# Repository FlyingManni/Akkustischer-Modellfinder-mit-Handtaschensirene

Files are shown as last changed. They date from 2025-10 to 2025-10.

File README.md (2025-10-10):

# Modellfinder (Ansteuerung eines Taschenalarms)

Um verloren gegangene Modelle leichter wiederzufinden (besonders im Maisfeld), kam die Idee,  
einen Taschenalarm zu verwenden. Um diesen gezielt auszulösen, benötigt man eine entsprechende  
Ansteuerung — hier kommt der **Tiny45 Modellfinder** zum Einsatz.

---

## 🧭 Tiny45 Steuerung

Der Modellfinder wird über einen freien Empfängerkanal gesteuert.  
Hierbei gibt es vier mögliche Zustände:

1. **Empfängersignal kleiner 1,4 ms**  
   → Schaltet den Alarm scharf und ist ausgeschaltet.  
   Solange nicht mindestens einmalig ein Signal unter 1,4 ms anlag, ist keine Alarmierung möglich.  
   Wenn der Alarm *scharf* und ausgeschaltet ist, leuchtet die **Status-LED dauerhaft**.

2. **Signal zwischen 1,4 und 1,7 ms**  
   → Das sollte auch die *Failsafe-Einstellung* sein.  
   Liegt dieses Signal an, startet ein **1-minütiger Timer**.  
   Nach Ablauf von 1 Minute wird der Alarm ausgelöst.  
   Während der Timer läuft, **blinkt die Status-LED schnell**.

3. **Signal über 1,7 ms**  
   → Es wird **sofort Alarm ausgelöst**.  
   Die **Status-LED blinkt langsam**.

4. **Kein Signal mehr vom Empfänger**  
   (z. B. wenn der Flugakku vom Modell getrennt wurde)  
   → Ablauf wie bei Zustand 2.

> 🧩 **Anmerkung:**  
> Zustände 2 bis 4 sind erst möglich, wenn zuvor einmal Zustand 1 hergestellt wurde  
> (also ein Empfängersignal unter 1,4 ms anlag).

---

## 🔌 Anschlussübersicht

| Pin | Funktion / Anschlussbeschreibung |
|---|---|
| **RC-Signal** | An einen Empfängerausgang (Signal) anschließen |
| **RC-GND** | Masse des Empfängerausgangs |
| **+UB** | Betriebsspannung des Alarmgebers **max. 5V** (nicht direkt an Batterie-Plus anschließen, sondern an die Buchse, über die der Alarm ursprünglich ausgelöst wird – sonst ist die Steuerung ständig aktiv und die Batterie bald leer) |
| **Alarm** | Schaltet gegen Masse – hier wird die vorhandene Alarmschaltung angeschlossen |
| **GND** | Direkt an den Minuspol der Batterie anschließen |

---

## 📦 Tiny45 Steuerung

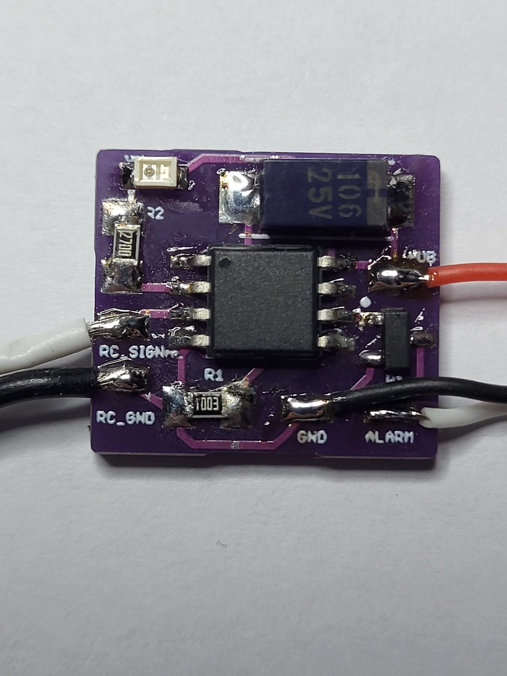
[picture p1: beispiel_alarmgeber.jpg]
Beispiel-Alarmgeber


---

## 📘 Lizenz & Hinweise

Dieses Projekt ist für den privaten Gebrauch gedacht.  
Verwendung auf eigene Verantwortung.

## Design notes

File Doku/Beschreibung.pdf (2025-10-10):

### Modellfinder (Ansteuerung eines Taschenalarms)

Um verloren gegangene Modelle leichter wieder zu finden (besonders im Maisfeld), kam die Idee einen Taschenalarm zu verwenden. Um diesen gezielt auszulösen benötigt man eine entsprechende Ansteuerung, hier kommt der Tiny45 Modellfinder zum Zug.

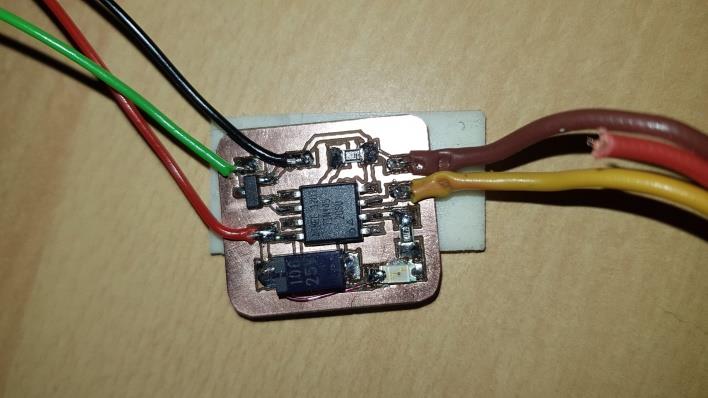
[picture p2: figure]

Tiny45 Steuerung 1

Der Modellfinder wird über einen freien Empfängerkanal gesteuert. Hierbei gibt es 4 mögliche Zustände:

1. Empfängersignal kleiner 1,4 ms -> schaltet den Alarm scharf und ist ausgeschaltet. Solange nicht mindestens einmalig ein Signal unter 1,4 ms angelegen hat ist keine Alarmierung möglich. Wenn der Alarm „scharf“ und ausgeschaltet ist leuchtet die Status-LED dauerhaft.
2. Signal zwischen 1,4 und 1,7 ms -> das sollte auch die Failsafe-Einstellung sein. Liegt dieses Signal an startet ein 1 minütiger Timer. Nach Ablauf von 1 Minute wird Alarm ausgelöst. Während der Timer läuft blinkt die Status-LED schnell.
3. Signal über 1,7 ms -> es wird sofort Alarm ausgelöst. Die Status-LED blinkt langsam.
4. Kein Signal mehr vom Empfänger (Flugakku wurde vom Modell getrennt) -> Ablauf wie bei 2.

Anmerkung: Zustände 2 bis 4 sind erst möglich wenn zuvor einmal Zustand 1 hergestellt wurde, also ein Empfängersignal unter 1,4 ms.

Verbunden wird die Steuerung wie folgt:

Pin „RC-Signal“ an einen Empfängerausgang (Signal)
Pin „RC-GND“ Masse des Empfängerausgangs
Pin „+UB“ an die Betriebsspannung des Alarmgebers, hier ist darauf zu achten nicht direkt an den Pluspol der Batterie anzuschließen sondern an die entsprechende Buchse durch den ursprünglich der Alarm ausgelöst wird, sonst ist die Steuerung immer „an“ und die Batterie bald leer.
Pin „Alarm“ schaltet gegen „Masse“, d.h. hier wird die vorhandene Alarmschaltung angeschlossen. Pin „GND“ wird direkt an den Minuspol der Batterie angeschlossen.

Beispiel eines Alarmgebers wie man ihn in diversen Verkaufsportalen kaufen kann:

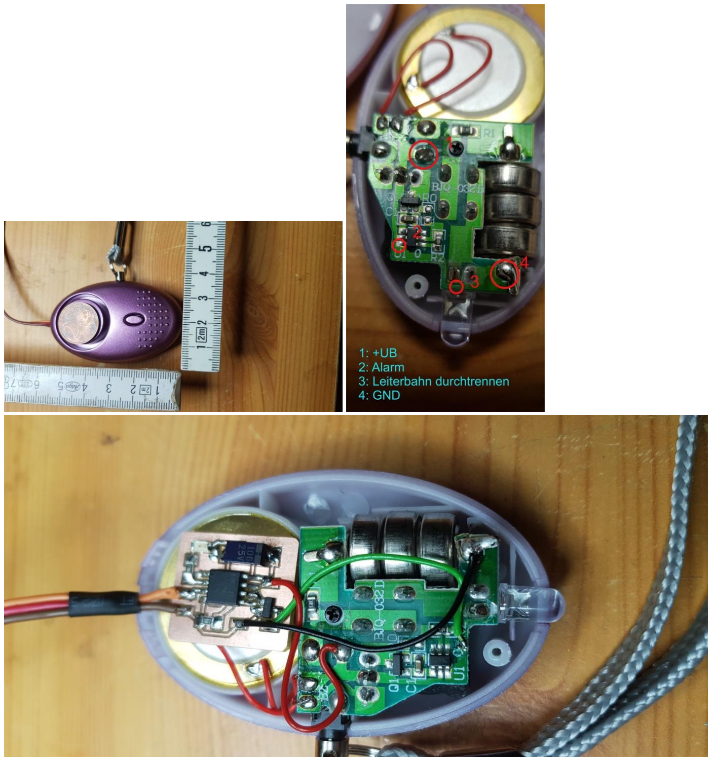
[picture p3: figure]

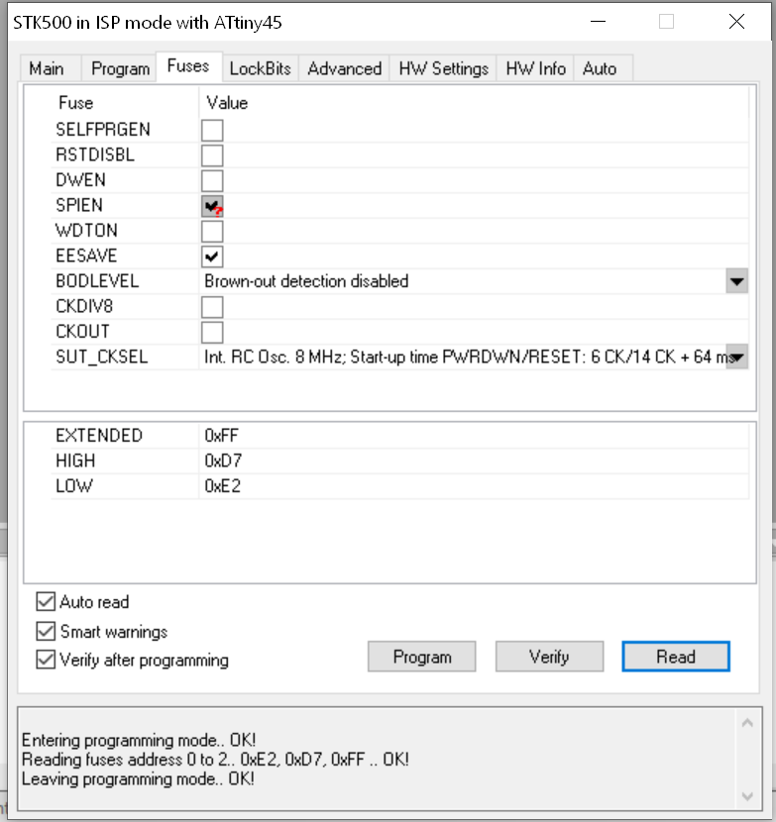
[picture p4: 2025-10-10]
Hex/Modellfinder_Tiny_Fuses.PNG

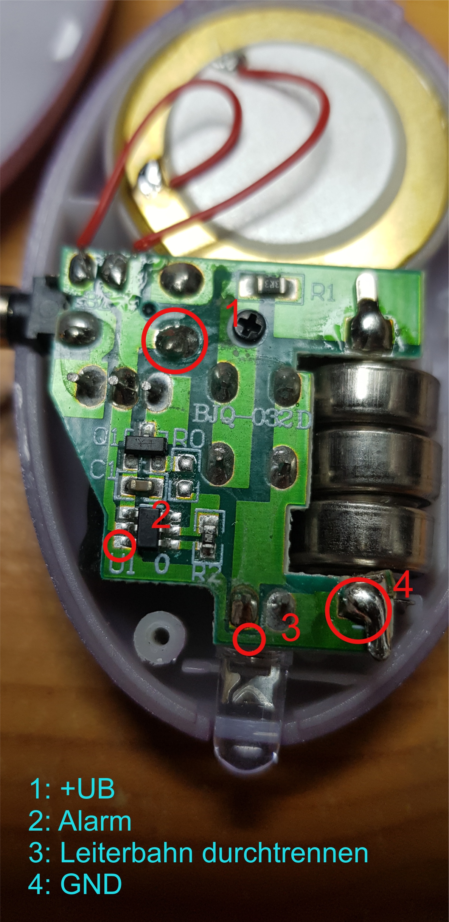
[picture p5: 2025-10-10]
Doku/Anschluesse.jpg

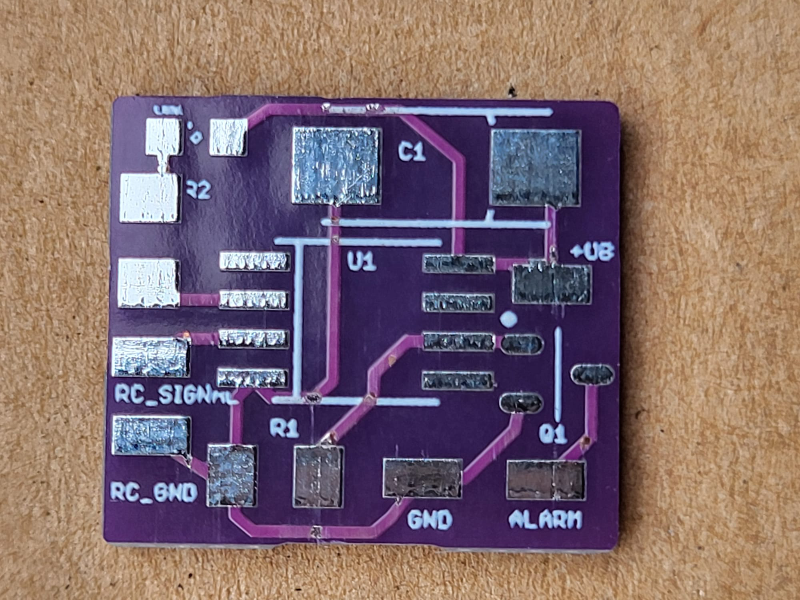
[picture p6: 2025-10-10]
Eagle/Platine.jpeg

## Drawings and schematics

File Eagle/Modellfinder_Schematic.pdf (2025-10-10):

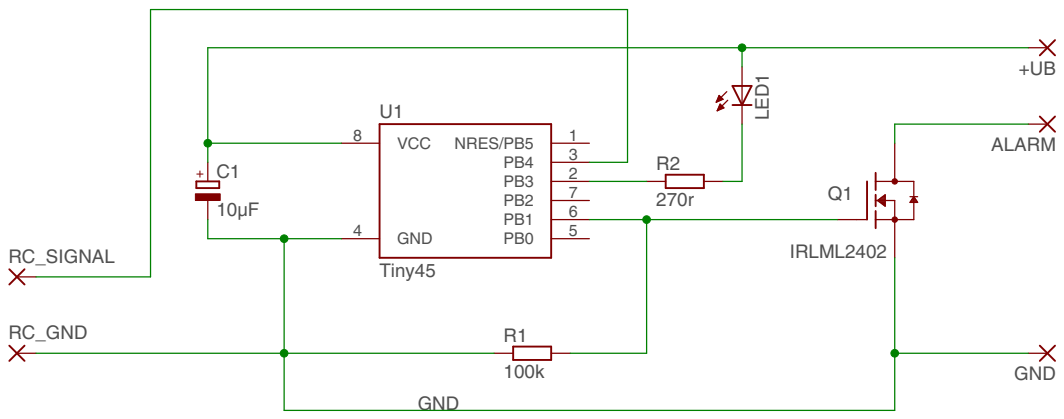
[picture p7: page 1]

Document Number: | REV:

Date: 23.10.2020 16:31 | Sheet: 1/1

23.10.2020 16:32 D:\Tortoise\Modellfinder\Eagle\Modellfinder.sch (Sheet: 1/1)

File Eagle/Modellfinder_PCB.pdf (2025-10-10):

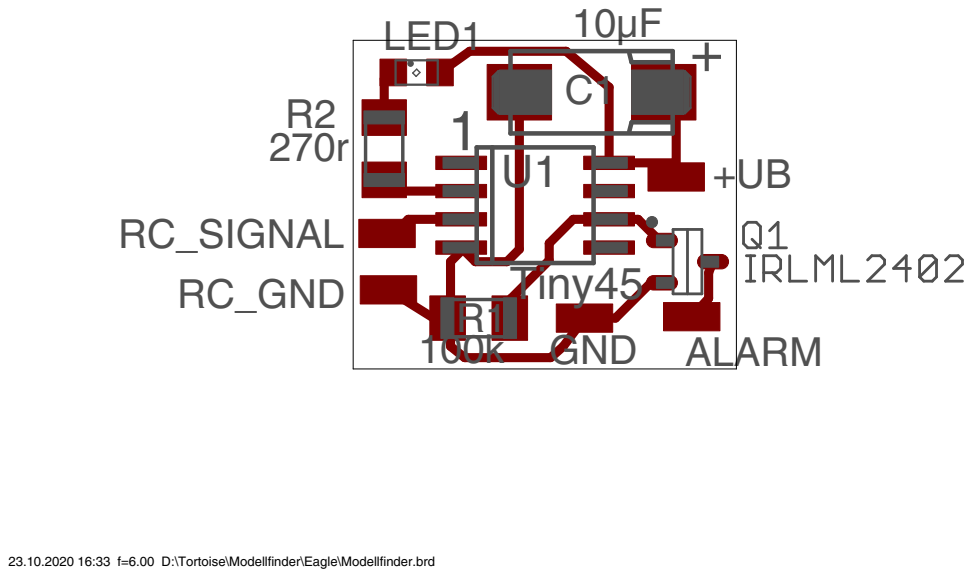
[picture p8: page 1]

23.10.2020 16:33 f=6.00 D:\Tortoise\Modellfinder\Eagle\Modellfinder.brd

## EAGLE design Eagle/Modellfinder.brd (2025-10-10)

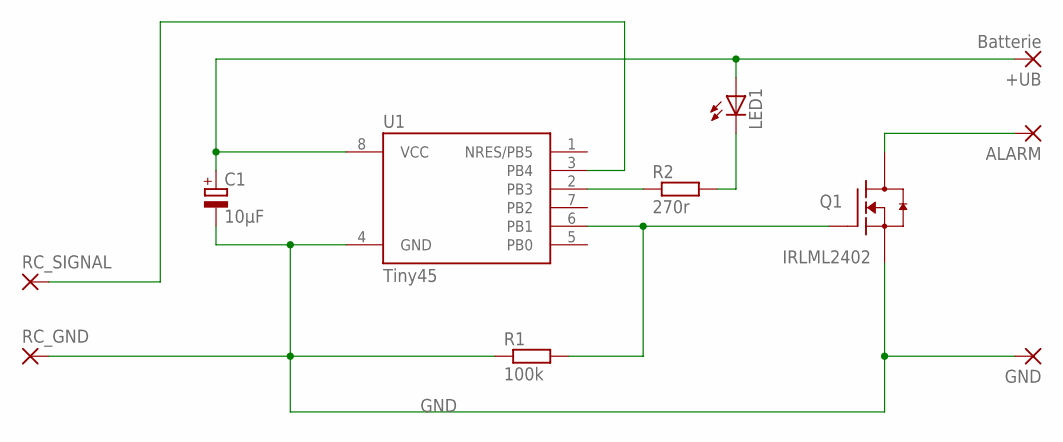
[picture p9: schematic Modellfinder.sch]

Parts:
+UB: Batterie; SMD1,27-2,54
ALARM: SMD2; SMD1,27-2,54
C1: 10µF; 085CS_1AR
GND: SMD2; SMD1,27-2,54
LED1: LEDSML0805; SML0805
Q1: IRLML2402; SOT95P280X135-3N
R1: 100k; M1206
R2: 270r; M1206
RC_GND: SMD2; SMD1,27-2,54
RC_SIGNAL: SMD2; SMD1,27-2,54
U1: Tiny45; SOIC8_EIAJ_208MIL

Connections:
GND: C1.-, GND.1, Q1.2 (S), R1.1, RC_GND.1, U1.4 (GND)
unnamed: Q1.1 (G), R1.2, U1.6 (PB1)
unnamed: LED1.C, R2.2
unnamed: +UB.1, C1.+, LED1.A, U1.8 (VCC)
unnamed: ALARM.1, Q1.3 (D)
unnamed: RC_SIGNAL.1, U1.3 (PB4)
unnamed: R2.1, U1.2 (PB3)

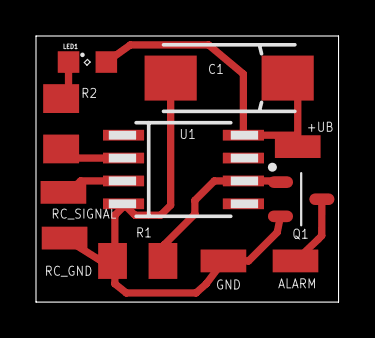
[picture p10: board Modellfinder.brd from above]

Board: 2 copper layers, 16.8 x 14.8 mm, 11 parts (0 on the bottom side), 7 nets.

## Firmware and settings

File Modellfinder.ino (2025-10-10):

/* RC-Steuerung für Taschenalarm von Manfred Stratmann
 *  atTiny 45 mit 8 Mhz internal Clock 
 *
 * Es muss mindestens einmal ein Signal unter 1,4ms vom Empfänger gekommen sein
 * damit sich die Steuerung "scharf" schaltet, ohne vorheriges Signal wird kein
 * Alarm ausgelöst.
 * Am Empfänger sollte ein Failsave von 1,5ms aktiviert sein. Im Bereich zwischen
 * 1,4 und 1,7ms startet ein 1 Minütiger Timer nach dessen Ablauf Alarm ausgelöst
 * wird.
 * Bei Signal über 1,7ms wird sofort Alarm ausgelöst. Auch wenn vom Empfänger gar 
 * kein Signal mehr kommt wird nach 1 Minute Alarm ausgelöst (sofern der einmal "scharf"
 * geschaltet wurde).
 * 
 * Anzeigen der Status-Led:
 * aus : Alarmgeber ist nicht "scharf", es wird überhaupt kein Alarm ausgelöst
 * leuctet dauerhaft: Alarm ist "scharf" und gibt kein Alarm aus
 * blinkt schnell: 1 minuten Timer aktiv, nach Ablauf wird Alarm ausgelöst
 * blinkt langsam: Alarm ausgelöst, es sollte was zu hören sein ;-)
 * 
 */

#define INPIN 4       // Tiny45 PB4 (Pin 3) 
#define alarmpin 1    // Tiny45 PB1 (Pin 6) 
#define StatusLed 3   // Tiny45 PB3 (Pin 2) 
#define StatusLedOn digitalWrite(StatusLed, LOW)
#define StatusLedOff digitalWrite(StatusLed, HIGH)
#define ToggleStatusLed PINB |= 1<<StatusLed
#define AlarmOn digitalWrite(alarmpin, HIGH);
#define AlarmOff digitalWrite(alarmpin, LOW);

bool AlarmScharf = false;
bool DoAlarm = false;
bool CheckAlarm = false;
unsigned long res;
unsigned long countDownStart = millis();
const unsigned long CountDownTimer = 60;  // 60 Sekunden
unsigned long BlinkStart = millis();
unsigned long BlinkTime;

void setup() {
   pinMode(INPIN, INPUT);
   pinMode(StatusLed, OUTPUT);
   pinMode(alarmpin, OUTPUT);
   digitalWrite(alarmpin, LOW);
   StatusLedOff;
}

bool inRange(unsigned long val, unsigned long minimum, unsigned long maximum)
{
  return ((minimum <= val) && (val <= maximum));
}

void StatusBlink(bool blinkFast)
{
  unsigned int TimeChangeStatus = 500;
  if (blinkFast) { TimeChangeStatus = 200; } 
  BlinkTime = (millis() - BlinkStart);
  if (BlinkTime >  TimeChangeStatus) {
    ToggleStatusLed;
    BlinkStart = millis();
  }
}

void MakeAlarm(void) {
  AlarmOn;
  StatusBlink(false);
}

void WarnungIfCountdownRunning(void) {
  StatusBlink(true);
}

void ResetContdown(void) {
  countDownStart = millis();
}

void loop() {
  CheckAlarm = true;
  res = pulseIn(INPIN, HIGH, 30000UL);
  if (res) {
      if (inRange(res, 900, 1399) == true) {
        AlarmScharf = true;
        StatusLedOn;
        AlarmOff;
        DoAlarm = false;
        CheckAlarm = false;
        ResetContdown();
        BlinkStart = millis();
      }
  } else
  {
     res = 30000;
  }  

  if ((AlarmScharf == true) && CheckAlarm) {
    if (((res > 2500) || (inRange(res, 1400, 1700) == true)) && (((millis() - countDownStart) / 1000) > CountDownTimer)) { DoAlarm = true; }  // kein Signal mehr
    if (inRange(res, 1701, 2100) == true) { // Signal am Sender ausgelöst
       DoAlarm = true; 
       ResetContdown();
    }  
    if (DoAlarm == true) { 
      MakeAlarm(); 
    } 
    else { 
      AlarmOff; 
      WarnungIfCountdownRunning();
    }
  }
  else ResetContdown();
}
